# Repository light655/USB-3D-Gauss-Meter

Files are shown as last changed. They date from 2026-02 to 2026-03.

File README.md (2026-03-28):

# USB 3D-Gauss Meter

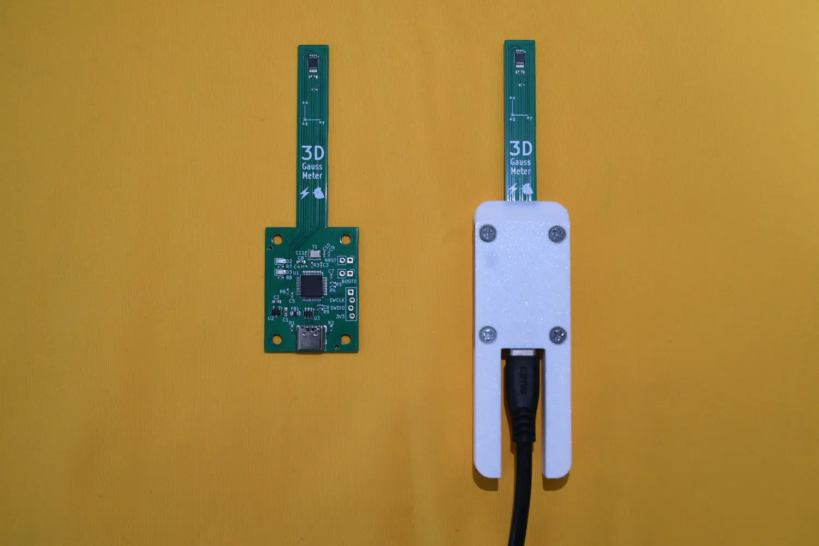
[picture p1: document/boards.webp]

This project is a USB 3D-Gauss Meter based on Texas Instrument's TMAG5170 Hall Sensor.
The Gauss Meter is powered by an STM32, which sends the measured data through USB.
A Python GUI client is provided to show the measured results.
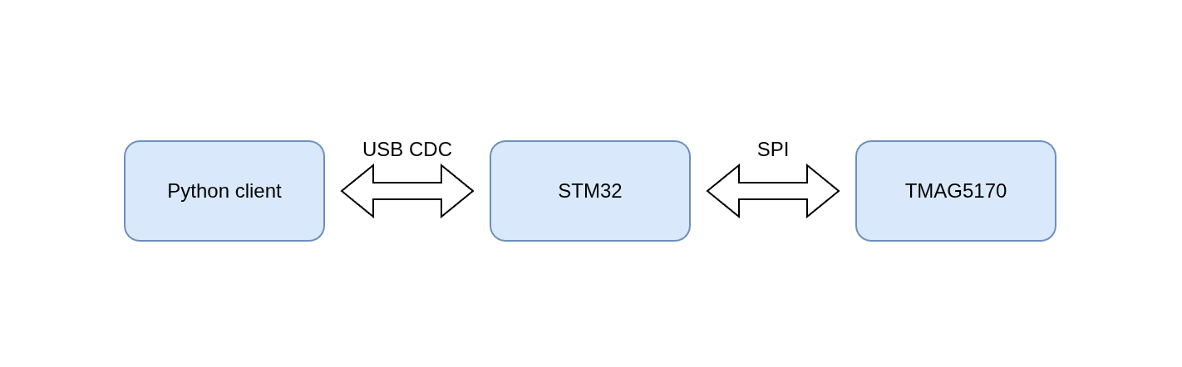
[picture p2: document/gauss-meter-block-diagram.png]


## Files
- document: Images used in this README file.
- firmware: Source code of the firmware for the STM32.
- hardware: Kicad project of the PCB design.
- python-client: The Python GUI client. Please visit [my website](https://light655.github.io/Product/gauss_meter.html) for instructions.
- shell: The 3D-printed shell model.

## Python GUI client
Please visit [my website](https://light655.github.io/Product/gauss_meter.html) for instructions.

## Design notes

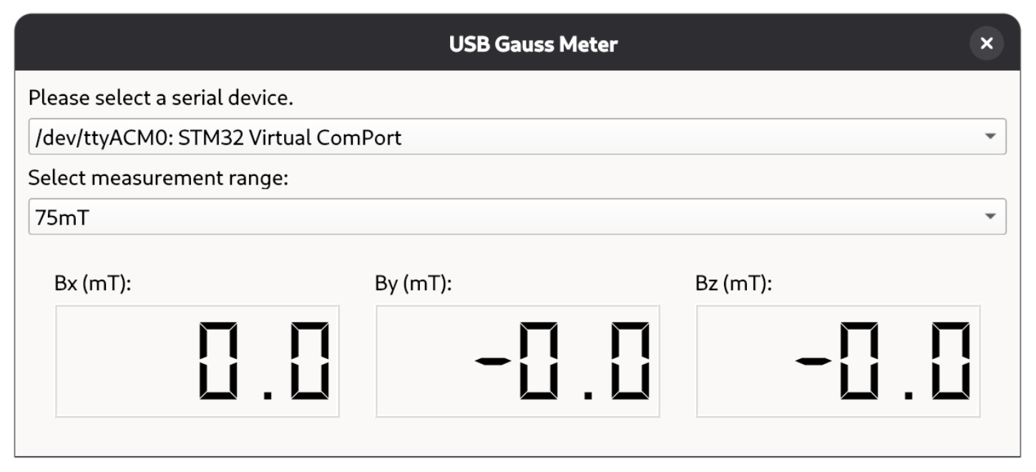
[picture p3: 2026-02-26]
document/client.png

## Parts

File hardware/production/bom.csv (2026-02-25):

Designator | Footprint | Quantity | Value | LCSC Part #
C1, C12, C8 | 0603 | 3 | 1u | C15849
C10, C11 | 0402 | 2 | 15p | C1548
C2 | 0603 | 1 | 10u | C96446
C3, C4, C5, C6, C7, C9 | 0402 | 6 | 100n | C307331
D2 | 0805 | 1 | LED | C2297
D3 | 0805 | 1 | LED | C84256
FB1 | 0805 | 1 | FerriteBead_Small | C1015
J1 | USB_C_Receptacle_XKB_U262-16XN-4BVC11 | 1 | USB_C_Receptacle_USB2.0_16P | C319148
J2, J3 | PinHeader_1x02_P2.54mm_Vertical | 2 | Conn_01x02_Pin
J4 | zigzag_pin_header_2.545mm_4p | 1 | Conn_01x04_Pin
R1, R2, R7, R8 | 0402 | 4 | 5.1k | C25905
R10, R4, R5, R6 | 0402 | 4 | 10k | C25744
R3 | 0402 | 1 | 470 | C25117
R9 | 0402 | 1 | 1.5k | C25867
U1 | LQFP-48_7x7mm_P0.5mm | 1 | STM32F103C8Tx | C8734
U2 | SOT-23-3 | 1 | XC6206P332MR | C5446
U3 | SOT-23-6 | 1 | SRV05-4 | C85364
U4 | VSSOP-8_3x3mm_P0.65mm | 1 | TMAG5170-A2 | C3716101
Y1 | Crystal_SMD_3225-4Pin_3.2x2.5mm | 1 | 16MHz | C13738

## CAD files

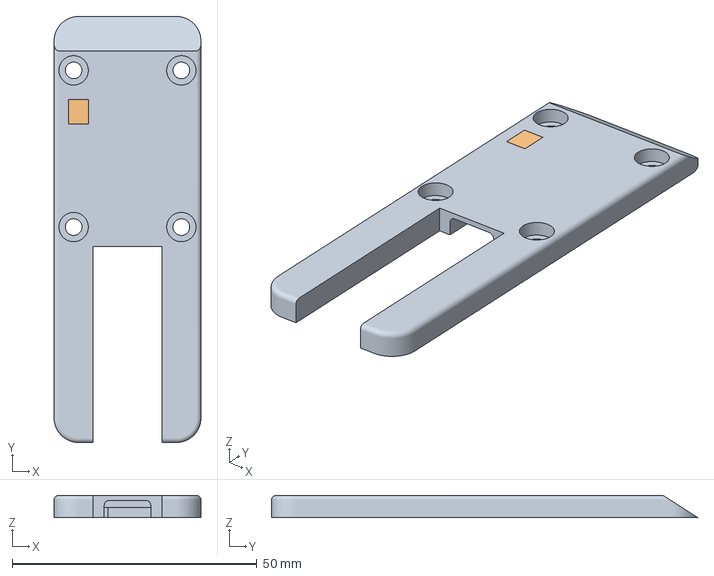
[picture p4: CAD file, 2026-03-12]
shell/shell_v2-Top.3mf
30.0 x 87.0 x 4.50 mm

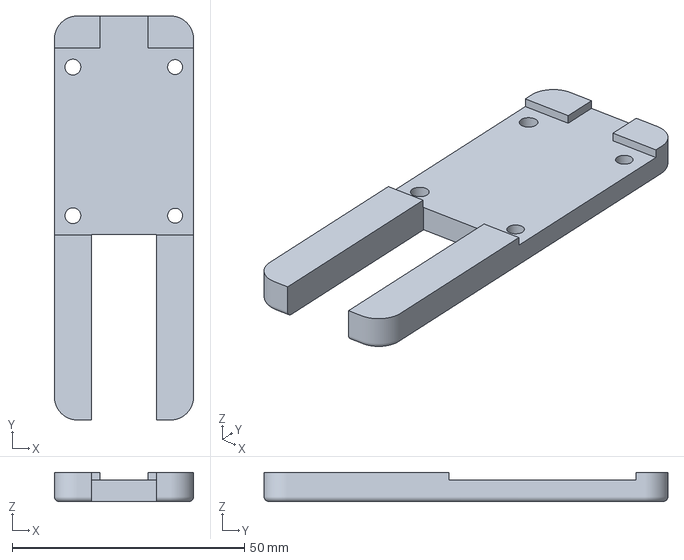
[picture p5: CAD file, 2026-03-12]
shell/shell_v2-Bottom.3mf
30.0 x 87.0 x 6.25 mm

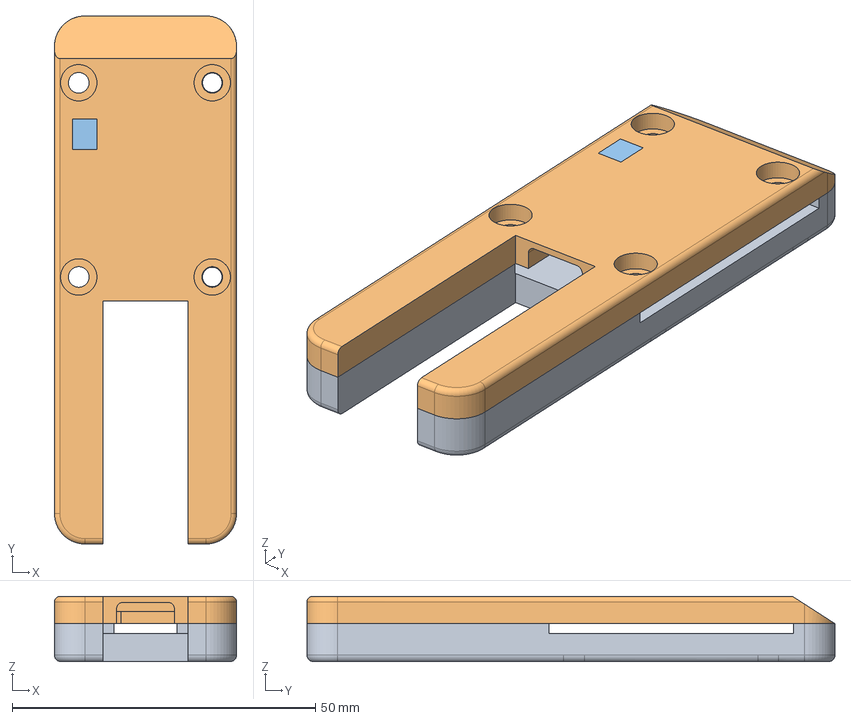
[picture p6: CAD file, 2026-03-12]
shell/shell_v2.FCStd
30.0 x 87.0 x 10.8 mm
Bottom
Top
LED_shield

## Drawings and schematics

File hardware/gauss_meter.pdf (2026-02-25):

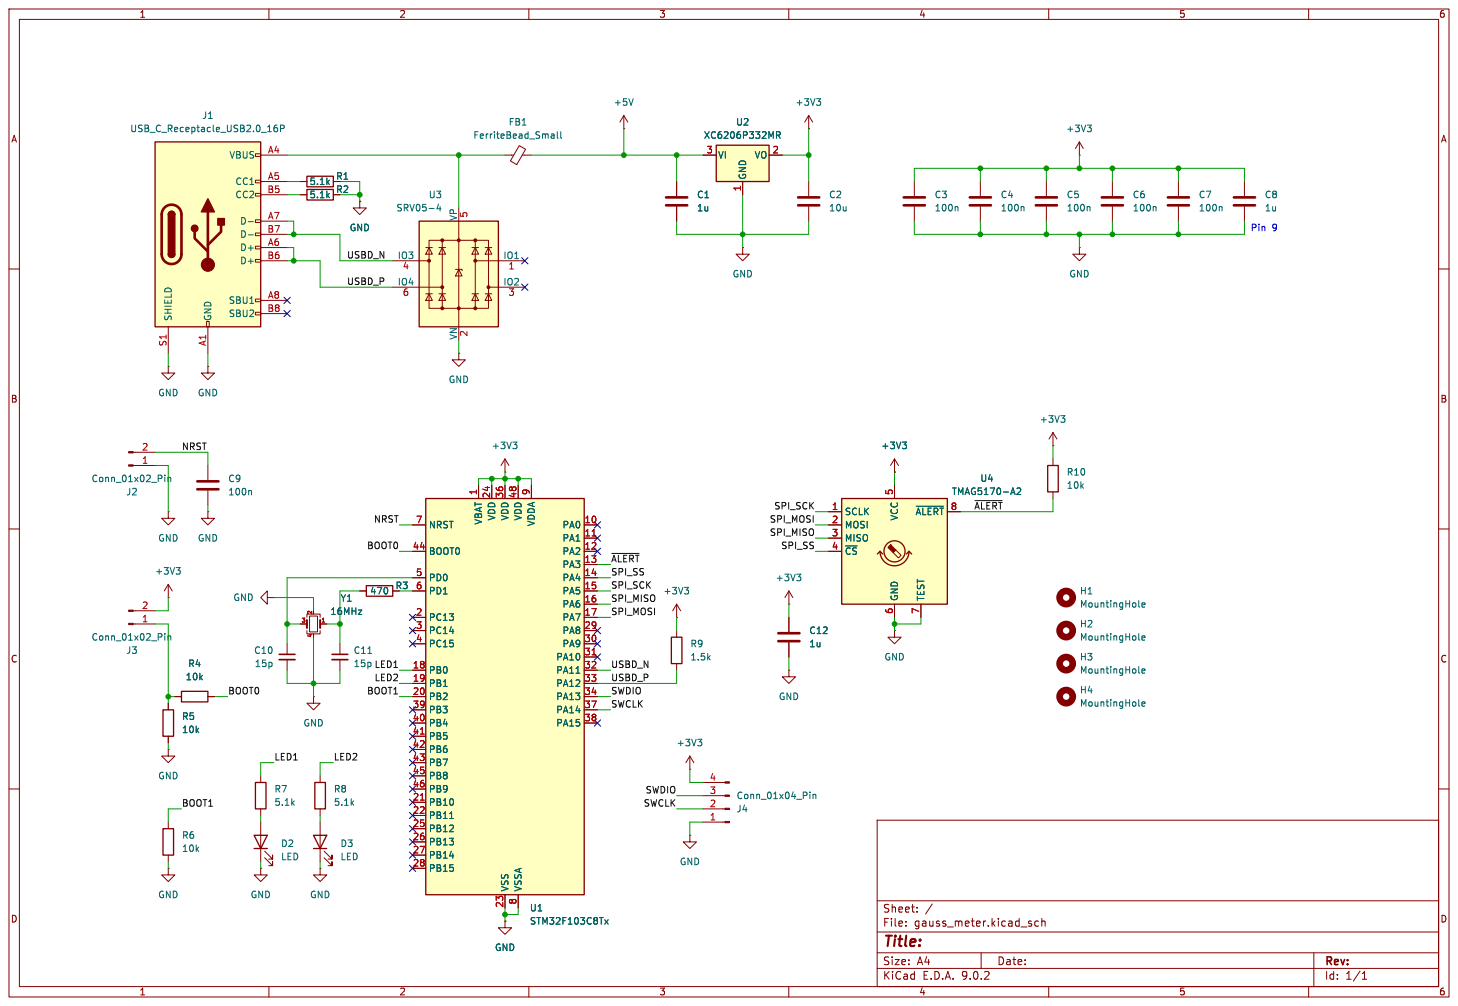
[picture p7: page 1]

Id: 1/1 Title: File: gauss_meter.kicad_sch Sheet: /

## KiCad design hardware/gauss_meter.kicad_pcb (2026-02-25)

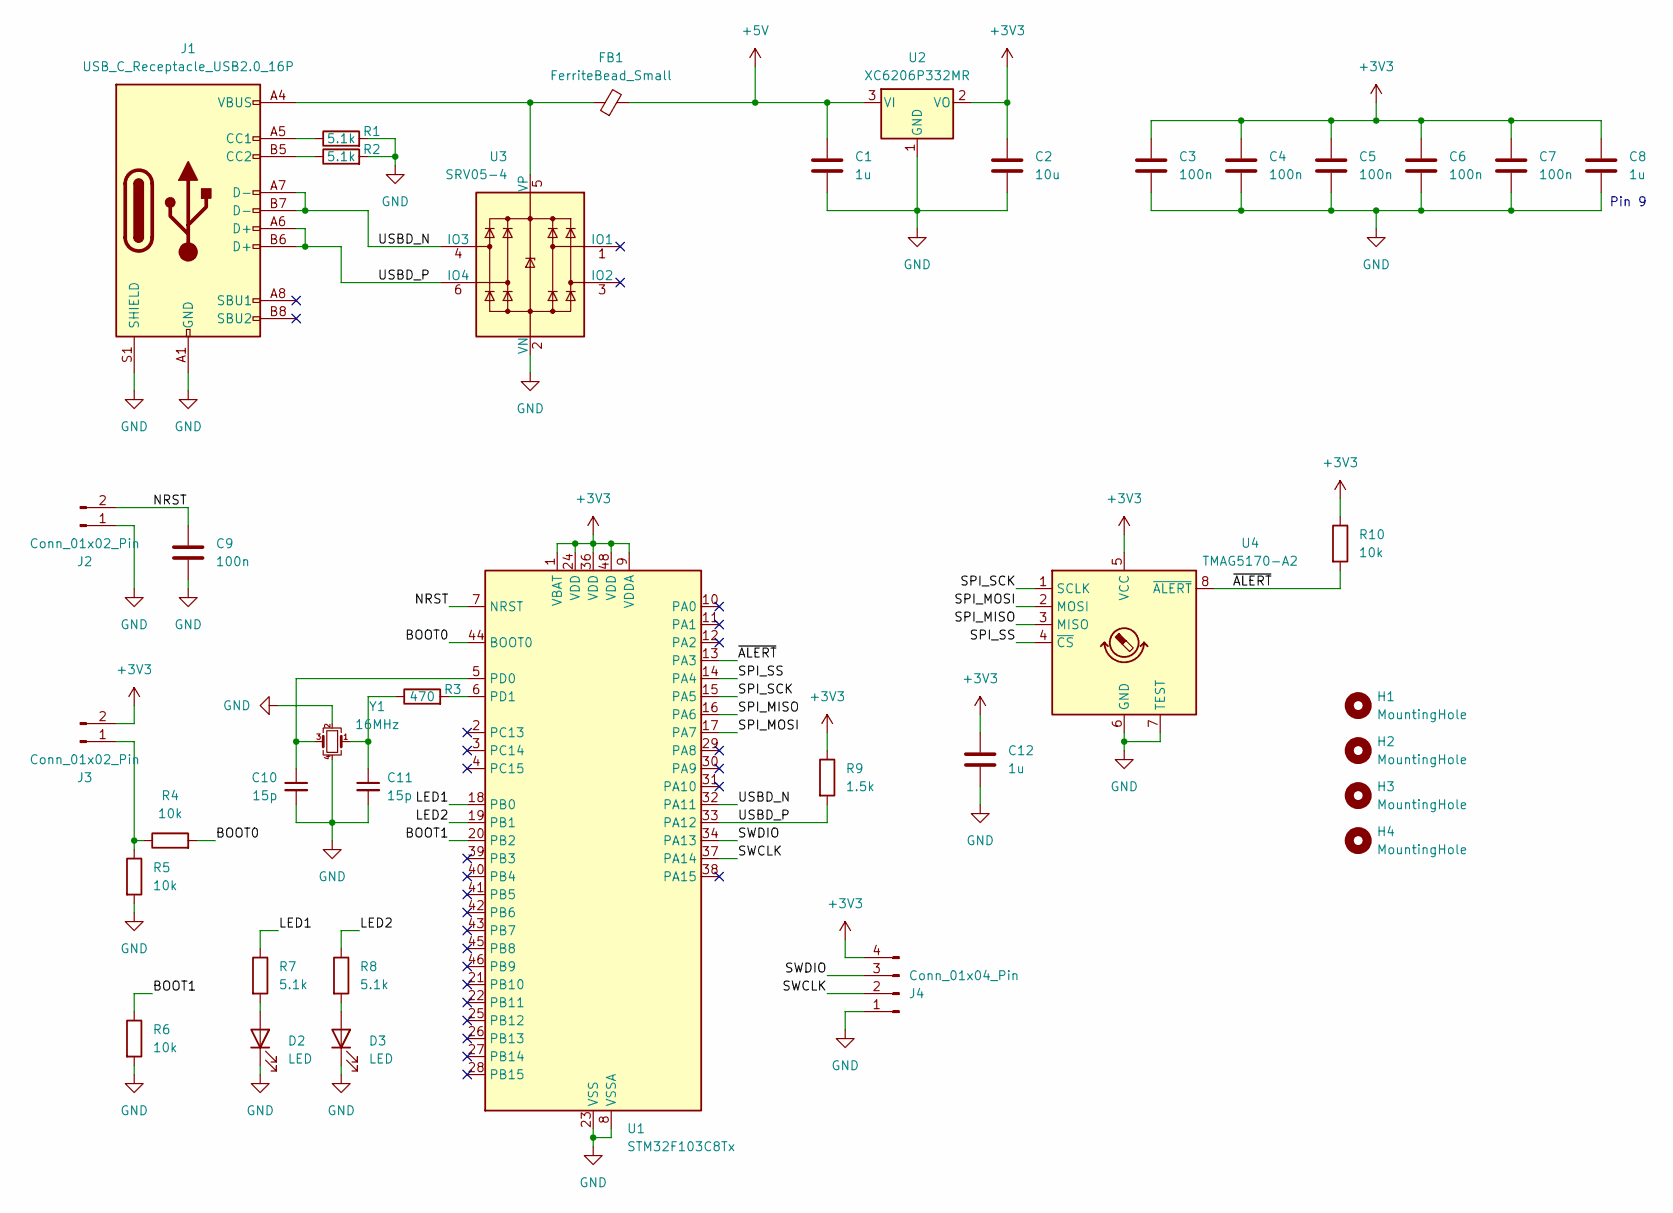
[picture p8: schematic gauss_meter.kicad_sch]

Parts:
C1, C8, C12: 1u; C_0603_1608Metric_Pad1.08x0.95mm_HandSolder; LCSC C15849
C2: 10u; C_0603_1608Metric_Pad1.08x0.95mm_HandSolder; LCSC C96446
C3, C4, C5, C6, C7, C9: 100n; C_0402_1005Metric_Pad0.74x0.62mm_HandSolder; LCSC C307331
C10, C11: 15p; C_0402_1005Metric_Pad0.74x0.62mm_HandSolder; LCSC C1548
D2: LED; LED_0805_2012Metric_Pad1.15x1.40mm_HandSolder; LCSC C2297
D3: LED; LED_0805_2012Metric_Pad1.15x1.40mm_HandSolder; LCSC C84256
FB1: FerriteBead_Small; L_0805_2012Metric_Pad1.15x1.40mm_HandSolder; LCSC C1015
H1, H2, H3, H4: MountingHole; MountingHole_3.2mm_M3
J1: USB_C_Receptacle_USB2.0_16P; USB_C_Receptacle_XKB_U262-16XN-4BVC11; LCSC C319148
J2, J3: Conn_01x02_Pin; PinHeader_1x02_P2.54mm_Vertical
J4: Conn_01x04_Pin; zigzag_pin_header_2.545mm_4p
R1, R2, R7, R8: 5.1k; R_0402_1005Metric_Pad0.72x0.64mm_HandSolder; LCSC C25905
R3: 470; R_0402_1005Metric_Pad0.72x0.64mm_HandSolder; LCSC C25117
R4, R5, R6, R10: 10k; R_0402_1005Metric_Pad0.72x0.64mm_HandSolder; LCSC C25744
R9: 1.5k; R_0402_1005Metric_Pad0.72x0.64mm_HandSolder; LCSC C25867
U1: STM32F103C8Tx; LQFP-48_7x7mm_P0.5mm; LCSC C8734
U2: XC6206P332MR; SOT-23-3; LCSC C5446
U3: SRV05-4; SOT-23-6; LCSC C85364
U4: TMAG5170-A2; VSSOP-8_3x3mm_P0.65mm; LCSC C3716101
Y1: 16MHz; Crystal_SMD_3225-4Pin_3.2x2.5mm; LCSC C13738

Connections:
+3V3: C2.1, C3.1, C4.1, C5.1, C6.1, C7.1, C8.1, C12.1, J3.2, J4.4, R9.1, R10.1, U1.1 (VBAT), U1.9 (VDDA), U1.24 (VDD), U1.36 (VDD), U1.48 (VDD), U2.2 (VO), U4.5 (VCC)
+5V: C1.1, FB1.2, U2.3 (VI)
/BOOT0: R4.2, U1.44 (BOOT0)
/BOOT1: R6.1, U1.20 (PB2)
/LED1: R7.1, U1.18 (PB0)
/LED2: R8.1, U1.19 (PB1)
/NRST: C9.1, J2.2, U1.7 (NRST)
/SPI_MISO: U1.16 (PA6), U4.3 (MISO)
/SPI_MOSI: U1.17 (PA7), U4.2 (MOSI)
/SPI_SCK: U1.15 (PA5), U4.1 (SCLK)
/SPI_SS: U1.14 (PA4), U4.4 (~CS)
/SWCLK: J4.2, U1.37 (PA14)
/SWDIO: J4.3, U1.34 (PA13)
/USBD_N: J1.A7 (D-), J1.B7 (D-), U1.32 (PA11), U3.4 (IO3)
/USBD_P: J1.A6 (D+), J1.B6 (D+), R9.2, U1.33 (PA12), U3.6 (IO4)
/~ALERT: R10.2, U1.13 (PA3), U4.8 (~ALERT)
GND: C1.2, C2.2, C3.2, C4.2, C5.2, C6.2, C7.2, C8.2, C9.2, C10.2, C11.2, C12.2, D2.1 (K), D3.1 (K), J1.A1 (GND), J1.A12 (GND), J1.B1 (GND), J1.B12 (GND), J1.S1 (SHIELD), J2.1, J4.1, R1.2, R2.2, R5.2, R6.2, U1.8 (VSSA), U1.23 (VSS), U1.35 (VSS), U1.47 (VSS), U2.1 (GND), U3.2 (VN), U4.6 (GND), U4.7 (TEST), Y1.2, Y1.4
unnamed: C11.1, R3.1, Y1.1
unnamed: D2.2 (A), R7.2
unnamed: D3.2 (A), R8.2
unnamed: J1.A5 (CC1), R1.1
unnamed: J1.B5 (CC2), R2.1
unnamed: J3.1, R4.1, R5.1
unnamed: C10.1, U1.5 (PD0), Y1.3
unnamed: R3.2, U1.6 (PD1)
unnamed: FB1.1, J1.A4 (VBUS), J1.A9 (VBUS), J1.B4 (VBUS), J1.B9 (VBUS), U3.5 (VP)

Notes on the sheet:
Pin 9

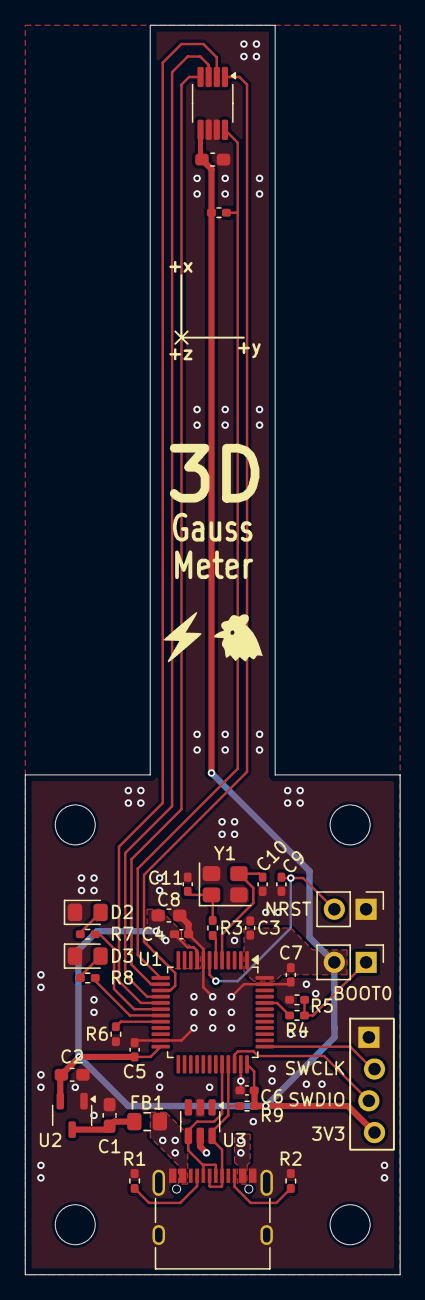
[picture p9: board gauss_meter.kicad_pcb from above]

Board: 2 copper layers, 30.0 x 100.0 mm, 38 parts (0 on the bottom side), 26 nets.

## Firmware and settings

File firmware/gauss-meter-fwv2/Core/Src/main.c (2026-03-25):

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
/* Includes ------------------------------------------------------------------*/
#include "main.h"
#include "usb_device.h"

/* USER CODE BEGIN Includes */

#include "usbd_cdc_if.h"
#include <stdint.h>
/* USER CODE END Includes */

SPI_HandleTypeDef hspi1;

/* USER CODE BEGIN PV */
uint8_t usb_tx_buf[USB_BUF_LEN];
uint16_t usb_tx_buf_len;

uint8_t usb_rx_buf[USB_BUF_LEN];
uint16_t usb_rx_buf_len;
volatile uint8_t usb_rx_flag = 0;

volatile uint8_t start_measurement_flag = 0;
volatile uint8_t alert_flag = 0;
/* USER CODE END PV */

void SystemClock_Config(void);
static void MX_GPIO_Init(void);
static void MX_SPI1_Init(void);
/* USER CODE BEGIN PFP */
void USB_RXCallback(uint8_t *buf, uint32_t *len) {
  memcpy(usb_rx_buf, buf, *len);
  if(*len <= USB_BUF_LEN) {
    usb_rx_buf[*len] = 0x00;
  }
  usb_rx_buf_len = *len;
  usb_rx_flag = 1;

  if(buf[0] == 'H') {
    start_measurement_flag = 1;   // set flag if received 'H' for start
  } else if(buf[0] == 'S') {
    start_measurement_flag = 0;   // reset flag if received 'S' for stop
  }                               // don't change flag value in other case
}

uint32_t GetMicros(void) {
  uint32_t ms;
  uint32_t st;
  uint32_t load = SysTick->LOAD;

  do {
    ms = HAL_GetTick();   // get current ms
    st = SysTick->VAL;
  } while(ms != HAL_GetTick());   // get new current ms if changed

  uint32_t ticks_per_us = SystemCoreClock / 1e6;

  return (ms * 1000) + (load - st) / ticks_per_us;
    // load - st due to the systick timer counts downwards
}
/* USER CODE END PFP */

/**
  * @brief  The application entry point.
  * @retval int
  */
int main(void)
{

  /* MCU Configuration--------------------------------------------------------*/

  /* Reset of all peripherals, Initializes the Flash interface and the Systick. */
  HAL_Init();

  /* Configure the system clock */
  SystemClock_Config();

  /* Initialize all configured peripherals */
  MX_GPIO_Init();
  MX_SPI1_Init();
  MX_USB_DEVICE_Init();
  /* USER CODE BEGIN 2 */
  app_main();             // actual main function
  /* USER CODE END 2 */

  /* Infinite loop */
  /* USER CODE BEGIN WHILE */
  while (1)
  {
    /* USER CODE END WHILE */

    /* USER CODE BEGIN 3 */
  }
  /* USER CODE END 3 */
}

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
/* USER CODE BEGIN 4 */
void HAL_GPIO_EXTI_Callback(uint16_t GPIO_Pin) {
  if(GPIO_Pin == GPIO_PIN_3) {      // interrupt from TMAG5170 alert pin
    alert_flag = 1;
  } else {
    __NOP();
  }
}
/* USER CODE END 4 */
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


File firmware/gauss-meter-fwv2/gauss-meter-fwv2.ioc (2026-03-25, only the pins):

Mcu.UserName=STM32F103C8Tx
PA11.Signal=USB_DM
PA12.Signal=USB_DP
PA13.Signal=SYS_JTMS-SWDIO
PA14.Signal=SYS_JTCK-SWCLK
PA3.Signal=GPXTI3
PA4.Signal=GPIO_Output
PA5.Signal=SPI1_SCK
PA6.Signal=SPI1_MISO
PA7.Signal=SPI1_MOSI
PB0.Signal=GPIO_Output
PB1.Signal=GPIO_Output
PD0-OSC_IN.Signal=RCC_OSC_IN
PD1-OSC_OUT.Signal=RCC_OSC_OUT

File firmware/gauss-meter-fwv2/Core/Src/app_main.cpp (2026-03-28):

#include "main.h"
#include "stm32f1xx_hal_gpio.h"
#include "usbd_cdc_if.h"
#include "TMAG5170.hpp"
#include <cstdio>
#include <cstring>
#include <stdint.h>

union measure_frame {   // frame to hold 1 measurement data
    struct {
        uint32_t t1;
        int16_t Bx;
        int16_t By;
        int16_t Bz;
    } S;
    char arr[10];       // unioned with char array for easier iteration when sending data through USB
};

extern uint8_t usb_tx_buf[USB_BUF_LEN];
extern uint16_t usb_tx_buf_len;

extern uint8_t usb_rx_buf[USB_BUF_LEN];
extern uint16_t usb_rx_buf_len;
extern uint8_t usb_rx_flag;

extern volatile uint8_t start_measurement_flag;
extern volatile uint8_t alert_flag;

void app_main(void) {
    TMAG5170 myTMAG;
    measure_frame frames[USB_BATCH_SIZE];

    myTMAG.init();
    HAL_GPIO_WritePin(GPIOB, GPIO_PIN_1, GPIO_PIN_SET);

    while(1) {
        if(start_measurement_flag) {
            usb_rx_flag = 0;   // reset usb received flag

            uint8_t sr_byte = usb_rx_buf[1];
            uint8_t range_byte = usb_rx_buf[2];
            int32_t max_measurements = (usb_rx_buf[6] << 24) | (usb_rx_buf[5] << 16) | (usb_rx_buf[4] << 8) | usb_rx_buf[3];

            switch(sr_byte) {
            case 0:
                myTMAG.setConversionAverage(CONV_AVG_1x);
                break;
            case 1:
                myTMAG.setConversionAverage(CONV_AVG_2x);
                break;
            case 2:
                myTMAG.setConversionAverage(CONV_AVG_4x);
                break;
            case 3:
                myTMAG.setConversionAverage(CONV_AVG_8x);
                break;
            case 4:
                myTMAG.setConversionAverage(CONV_AVG_16x);
                break;
            default:
                myTMAG.setConversionAverage(CONV_AVG_32x);
            }

            switch(range_byte) {
            case 0:
                myTMAG.setMagneticRange(X_RANGE_75mT, Y_RANGE_75mT, Z_RANGE_75mT);
                break;
            case 1:
                myTMAG.setMagneticRange(X_RANGE_100mT, Y_RANGE_100mT, Z_RANGE_100mT);
                break;
            case 2:
                myTMAG.setMagneticRange(X_RANGE_150mT, Y_RANGE_150mT, Z_RANGE_150mT);
                break;
            default:
                myTMAG.setMagneticRange(X_RANGE_75mT, Y_RANGE_75mT, Z_RANGE_75mT);
            }

            CDC_Transmit_FS((uint8_t*)"D", 1);  // confirm setting

            myTMAG.enableMagneticChannel(true, true, true);
            myTMAG.setOperatingMode(OPERATING_MODE_ActiveMeasureMode);
            myTMAG.enableAlertOutput(true);

            HAL_GPIO_WritePin(GPIOB, GPIO_PIN_0, GPIO_PIN_SET); // measuring indicator
            uint32_t t0 = GetMicros();

            int i = 0;
            int index;
            while(i < max_measurements && start_measurement_flag) {
                while(!alert_flag && start_measurement_flag);   // wait for alert flag to be set by EXTI interrupt
                if(!start_measurement_flag) break;
                alert_flag = 0;    // reset alert flag

                index = i % USB_BATCH_SIZE;
                // frames[i % USB_BATCH_SIZE].S.t1 = HAL_GetTick() * 1000; // temporary solution
                frames[index].S.t1 = GetMicros() - t0;
                frames[index].S.Bx = myTMAG.readXRaw();
                frames[index].S.By = myTMAG.readYRaw();
                frames[index].S.Bz = myTMAG.readZRaw();

                if((i + 1) % USB_BATCH_SIZE == 0) {   // send batch of measurements through USB
                    usb_tx_buf_len = USB_BATCH_SIZE * sizeof(measure_frame) + 1;
                    usb_tx_buf[0] = USB_BATCH_SIZE;  // first byte indicates number of frames in the batch
                    memcpy(usb_tx_buf + 1, frames, USB_BATCH_SIZE * sizeof(measure_frame));
                    CDC_Transmit_FS(usb_tx_buf, usb_tx_buf_len);
                }

                i++;
            }

            if((i % USB_BATCH_SIZE) != 0) {     // deal with remaining unsent data
                usb_tx_buf_len = (i % USB_BATCH_SIZE) * sizeof(measure_frame) + 1;
                usb_tx_buf[0] = i % USB_BATCH_SIZE;
                memcpy(usb_tx_buf + 1, frames, (i % USB_BATCH_SIZE) * sizeof(measure_frame));
                CDC_Transmit_FS(usb_tx_buf, usb_tx_buf_len);
            }

            myTMAG.enableMagneticChannel(false, false, false);
            myTMAG.setOperatingMode(OPERATING_MODE_ConfigurationMode);
            myTMAG.enableAlertOutput(false);

            HAL_GPIO_WritePin(GPIOB, GPIO_PIN_0, GPIO_PIN_RESET);   // turn off measuring indicator

            start_measurement_flag = 0;
        }
    }
}

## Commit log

2026-02-25 First commit.
    [bom.csv, bottom_shell-Body.3mf, bottom_shell.FCStd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]
2026-02-26 Added README.
    [bottom_shell-Body.3mf, bottom_shell-Bottom.3mf, bottom_shell-Top.3mf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]
2026-03-11 Added logging functions.
    [bottom_shell-Bottom.3mf, bottom_shell-Top.3mf, bottom_shell.FCStd]
2026-03-12 LED lights up when measuring.
    [bottom_shell-Bottom.3mf, bottom_shell-Top.3mf, bottom_shell.FCStd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]
2026-03-12 Rearranged 3D printing model files.
    [bottom_shell-Bottom.3mf, bottom_shell-Top.3mf, bottom_shell.FCStd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]
2026-03-12 Added power status LED.
2026-03-25 Increased STM32 clock frequency to 72 MHz.
2026-03-28 Removed pause button.

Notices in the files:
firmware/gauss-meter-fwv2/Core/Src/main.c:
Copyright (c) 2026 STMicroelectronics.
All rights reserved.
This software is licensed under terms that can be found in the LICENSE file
